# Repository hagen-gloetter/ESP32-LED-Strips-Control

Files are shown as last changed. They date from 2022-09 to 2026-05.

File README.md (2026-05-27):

# ESP32 LED-Strips Control — Sternwarte Höfingen

> **[Deutsch](#deutsch)** · **[English](#english)**

---

## 🇩🇪 Deutsch

### Projektbeschreibung

Steuerung der Beleuchtung der [Sternwarte Höfingen](https://www.sternwarte-hoefingen.de) über drei RGB-LED-Streifen an einem ESP32. Das System unterstützt rotes Beobachtungslicht (schonend für die Dunkeladaption) und weißes Allgemeinlicht. Helligkeit und Farbe sind über Drucktasten, einen Drehgeber und eine eingebaute Weboberfläche (Port 80) einstellbar. Ein DHT11-Sensor misst Temperatur und Luftfeuchtigkeit und zeigt sie im Web-UI an.

---

### Hardware

| Komponente | Beschreibung |
|---|---|
| ESP32 AZ-Delivery D1 Mini | Hauptcontroller |
| 3× RGB-LED-Streifen | Common-cathode, PWM-gesteuert |
| 2× Drucktaster (NO) | Weiß-/Rotlicht-Toggle |
| 1× Drehgeber mit Taster | Helligkeit |
| 1× DHT11 | Temperatur + Luftfeuchtigkeit |

#### GPIO-Belegung

| GPIO | Signal | Komponente |
|---|---|---|
| 0 | DHT DATA | DHT11 |
| 27 | STRIP 1 R | LED-Strip 1 Rot |
| 25 | STRIP 1 G | LED-Strip 1 Grün |
| 32 | STRIP 1 B | LED-Strip 1 Blau |
| 22 | STRIP 2 R | LED-Strip 2 Rot |
| 21 | STRIP 2 G | LED-Strip 2 Grün |
| 17 | STRIP 2 B | LED-Strip 2 Blau |
| 19 | STRIP 3 R | LED-Strip 3 Rot |
| 18 | STRIP 3 G | LED-Strip 3 Grün |
| 26 | STRIP 3 B | LED-Strip 3 Blau |
| 13 | BUTTON_W | Weiß-Taster (T1) |
| 10 | BUTTON_R | Rot-Taster (T2) |
| 14 | BUTTON_D | Drehgeber-Taster |
| 33 | CLK | Drehgeber CLK |
| 34 | DT | Drehgeber DT |
| 2 | LED | Onboard-LED (Status) |

#### Verdrahtungsdiagramm

```mermaid
graph TD
    subgraph ESP32["ESP32 D1 Mini"]
        G0["GPIO 0"]
        G2["GPIO 2"]
        G10["GPIO 10"]
        G13["GPIO 13"]
        G14["GPIO 14"]
        G17["GPIO 17"]
        G18["GPIO 18"]
        G19["GPIO 19"]
        G21["GPIO 21"]
        G22["GPIO 22"]
        G25["GPIO 25"]
        G26["GPIO 26"]
        G27["GPIO 27"]
        G32["GPIO 32"]
        G33["GPIO 33"]
        G34["GPIO 34"]
    end

    DHT11["DHT11\nTemp + Humidity"]
    BW["Button Weiß\n(T1, PULL_UP)"]
    BR["Button Rot\n(T2, PULL_UP)"]
    BD["Rotary SW\n(PULL_UP)"]
    RCLK["Rotary CLK\n(IRQ)"]
    RDT["Rotary DT\n(IRQ)"]
    ONBLED["Onboard LED"]

    subgraph Strip1["LED Strip 1"]
        S1R["Red"]
        S1G["Green"]
        S1B["Blue"]
    end
    subgraph Strip2["LED Strip 2"]
        S2R["Red"]
        S2G["Green"]
        S2B["Blue"]
    end
    subgraph Strip3["LED Strip 3"]
        S3R["Red"]
        S3G["Green"]
        S3B["Blue"]
    end

    G0  -->|DATA| DHT11
    G2  --> ONBLED
    G13 -->|IN| BW
    G10 -->|IN| BR
    G14 -->|IN| BD
    G33 -->|IN| RCLK
    G34 -->|IN| RDT
    G27 -->|PWM| S1R
    G25 -->|PWM| S1G
    G32 -->|PWM| S1B
    G22 -->|PWM| S2R
    G21 -->|PWM| S2G
    G17 -->|PWM| S2B
    G19 -->|PWM| S3R
    G18 -->|PWM| S3G
    G26 -->|PWM| S3B
```

---

### Licht-Logik

| Aktion | Ergebnis |
|---|---|
| Weiß-Taster (kurz) | Weißlicht ON/OFF (Rot hat Vorrang) |
| Rot-Taster (kurz) | Rotlicht ON; schaltet Weiß ab wenn nötig |
| Weiß 2× schnell (<2 s) | Helligkeit 50% |
| Weiß 4× schnell (<2 s) | Helligkeit 25% |
| Weiß 10× schnell (<6 s) | Easter Egg: Rainbow |
| Rot 2× schnell (<2 s) | Helligkeit 50% |
| Rot 4× schnell (<2 s) | Helligkeit 25% |
| Rot 10× schnell (<6 s) | Easter Egg: Zufallsfarben |
| Weiß/Rot gehalten (>500 ms) | Hold-to-Dim bis Mindesthelligkeit |
| Drehgeber rechts | Helligkeit erhöhen (2^Wert, max 1024) |
| Drehgeber links | Helligkeit verringern |
| Auto-Off | Schaltet nach konfigurierbarer Zeit automatisch aus |

PWM-Frequenz: **7321 Hz** (Primzahl, verhindert Moire-Artefakte in Kameras und Augen)

---

### Software / Abhängigkeiten

| | |
|---|---|
| MicroPython-Firmware | ≥ v1.19.1 für ESP32 |
| `dht` | Built-in in MicroPython |
| `ujson` | Built-in in MicroPython |
| `network` | Built-in in MicroPython |
| `rotary.py` | Mitgeliefert (MIT License, Mike Teachman) |

---

### Konfiguration

#### Konstanten in `config.json`

Konstanten können in `config.json` angepasst werden (Fallback auf Defaults bei Fehler):

| Konstante | Standardwert | Beschreibung |
|---|---|---|
| `LOOP_MS` | `100` | Haupt-Loop-Takt in ms (10 Hz) |
| `WIFI_CHECK_TICKS` | `300` | WiFi-Check alle 300 × 100 ms = 30 s |
| `Brightness` | `1024` | Anfangshelligkeit (0–1023) |
| `Fade_speed` | `16` | Fade-Schrittgröße pro Timer-Tick (1–64) |
| `DebugLevel` | `4` | 1=Fehler, 2=Warn, 3=Info, 4=verbose |
| `auto_off_minutes` | `120` | Auto-Off Timer in Minuten (0 = deaktiviert) |
| `hostname` | `ESP32-Huettenlicht` | WiFi DHCP-Hostname |
| `rotary_encoder_enabled` | `0` | Drehgeber-Auswertung aktiv (`1`) oder deaktiviert (`0`) |

WDT-Timeout: **15 000 ms** (> WiFi-Connect-Timeout von 10 000 ms).

#### Secrets-Datei

Lege `secrets_wifi.json` auf dem Gerät an (Format wie `secrets_wifi_example.json`):

```json
{
    "MeinHeimnetzwerk": "MeinPasswort",
    "FallbackSSID": "FallbackPasswort"
}
```

Das Gerät scannt verfügbare Netze und verbindet sich automatisch mit dem ersten bekannten SSID.

---

### WebREPL

Einmalige Einrichtung (einmalig im REPL):

```python
import webrepl_setup
```

Passwort wird in `webrepl_cfg.py` gespeichert (Standard: `1234` – **bitte ändern**).

Danach erreichbar unter: `ws://<IP des ESP32>:8266`  
Tool: [http://micropython.org/webrepl/](http://micropython.org/webrepl/)

---

### Weboberfläche

Modernes, responsives Dark-Theme-UI (Astronomie-optimiert), vollständig self-contained (kein externes CSS/JS). Features:

- **Card-basiertes Layout** mit Flexbox/Grid (responsive, mobiltauglich)
- **HTML5 Color-Picker** mit Live-Farbvorschau und RGB-Nummernfeldern
- **Farb-Presets** als visuelles Button-Grid (Rot, Grün, Blau, Weiß, Gelb, Lila, Cyan, Orange)
- **Aktiver ON/OFF-State** mit visuellem Glow-Feedback
- **Verstecktes Easter-Egg-Panel** mit Rainbow/Random/Stop
- **Config-Seite** für Fade Speed, Auto-Off, Debug Level, Hostname, Rotary Encoder ON/OFF und Reset
- **Vanilla JS** (kein jQuery), Polling via `fetch()` alle 4 Sekunden

| URL-Pfad | Funktion |
|---|---|
| `/` | Haupt-UI (HTML) |
| `/?red=on` / `/?red=off` | Rotlicht ein/aus |
| `/?white=on` / `/?white=off` | Weißlicht ein/aus |
| `/?r=R&g=G&b=B` | RGB-Wert direkt setzen (0–255) |
| `/?easter=rainbow` / `random` / `off` | Easter Egg steuern |
| `/?config_save&fade=N&autooff=N&debug=N&host=X&rotary=0|1` | Konfiguration speichern |
| `/?reset=1` | ESP32 Neustart |
| `/config.html` | Konfigurationsseite |
| `/data.json` | Aktueller Status als JSON |
| `/web.css` | Stylesheet |
| `/debug.html` | Live-Debug-Log |
| `/logs.html` | Separate Logs-Webseite |
| `/logs.json` | Logs als JSON für Polling |

---

### Dateistruktur

```
code/
├── boot.py                  # Startup: startet WebREPL
├── main.py                  # Hauptanwendung (GPIO, Webserver, Loop)
├── config.json              # Konfigurationsdatei für Konstanten
├── class_pwm.py             # RGB-LED-Strip PWM-Treiber
├── class_debounce.py        # Software-Entprellung für Tasten
├── class_debug.py           # Ring-Buffer Debug-Logger
├── class_humidity_sensor.py # DHT11-Treiber
├── class_wifi_connection.py # Multi-SSID WiFi-Manager
├── class_rotary_encoder.py  # Drehgeber (ESP32 IRQ)
├── rotary.py                # Plattformunabhängige Basis-Klasse (extern)
├── rotary_encoder.py        # Standalone-Beispiel (nicht im Hauptpfad)
├── rotary_irq_esp.py        # Standalone-Beispiel (nicht im Hauptpfad)
├── web_html.py              # HTML/CSS/Debug-Templates
├── webrepl_cfg.py           # WebREPL-Passwort
└── secrets_wifi_example.json # Beispiel für WiFi-Zugangsdaten
```

---

### Flash / Deployment

**Firmware flashen (einmalig):**

```bash
pip install esptool
esptool.py --chip esp32 --port /dev/ttyUSB0 erase_flash
esptool.py --chip esp32 --port /dev/ttyUSB0 write_flash -z 0x1000 \
    esp32-20220618-v1.19.1.bin
```

**Dateien übertragen (mpremote):**

```bash
pip install mpremote
mpremote connect /dev/ttyUSB0 cp code/secrets_wifi.json :secrets_wifi.json
mpremote connect /dev/ttyUSB0 cp code/boot.py :boot.py
mpremote connect /dev/ttyUSB0 cp code/main.py :main.py
mpremote connect /dev/ttyUSB0 cp code/class_*.py :/
mpremote connect /dev/ttyUSB0 cp code/rotary.py :rotary.py
mpremote connect /dev/ttyUSB0 cp code/web_html.py :web_html.py
mpremote connect /dev/ttyUSB0 cp code/webrepl_cfg.py :webrepl_cfg.py
```

**Alternativ mit Thonny:** [https://thonny.org/](https://thonny.org/)

---

### Bekannte Einschränkungen / TODOs

- `Strip3` wird in der aktuellen Hauptschleife nicht über den Webserver-RGB-Pfad gesetzt (nur Strip 1 und 2). Geplant: Übergabe einer Strip-Liste.
- RGB-Eingabe im Web-UI akzeptiert Werte 0–255; intern wird 0–1023 verwendet (PWM-Auflösung ESP32). Die Webserver-Validierung begrenzt auf 255 — für volle Auflösung Code anpassen.
- `rotary_encoder.py` und `rotary_irq_esp.py` sind Standalone-Beispiele und kein Bestandteil des Hauptprogramms — können vom Gerät gelöscht werden.

---

### Changelog

Siehe [CHANGELOG.md](CHANGELOG.md).

---

### Lizenz

Siehe [LICENSE](LICENSE).

---
---

## 🇬🇧 English

### Project Description

Controls the lighting of the [Sternwarte Höfingen observatory](https://www.sternwarte-hoefingen.de) via three RGB LED strips driven by an ESP32. The system supports red observation light (preserves dark adaption) and white general lighting. Brightness and colour are adjustable via push buttons, a rotary encoder, and a built-in web interface on port 80. A DHT11 sensor measures ambient temperature and humidity, displayed in the web UI.

---

### Hardware

| Component | Description |
|---|---|
| ESP32 AZ-Delivery D1 Mini | Main controller |
| 3× RGB LED strip | Common-cathode, PWM-controlled |
| 2× push button (NO) | White/red light toggle |
| 1× rotary encoder with button | Brightness |
| 1× DHT11 | Temperature + humidity |

#### GPIO mapping

| GPIO | Signal | Component |
|---|---|---|
| 0 | DHT DATA | DHT11 |
| 27 | STRIP 1 R | LED Strip 1 Red |
| 25 | STRIP 1 G | LED Strip 1 Green |
| 32 | STRIP 1 B | LED Strip 1 Blue |
| 22 | STRIP 2 R | LED Strip 2 Red |
| 21 | STRIP 2 G | LED Strip 2 Green |
| 17 | STRIP 2 B | LED Strip 2 Blue |
| 19 | STRIP 3 R | LED Strip 3 Red |
| 18 | STRIP 3 G | LED Strip 3 Green |
| 26 | STRIP 3 B | LED Strip 3 Blue |
| 13 | BUTTON_W | White button (T1) |
| 10 | BUTTON_R | Red button (T2) |
| 14 | BUTTON_D | Rotary encoder push button |
| 33 | CLK | Rotary encoder CLK |
| 34 | DT | Rotary encoder DT |
| 2 | LED | On-board LED (status) |

#### Wiring Diagram

```mermaid
graph TD
    subgraph ESP32["ESP32 D1 Mini"]
        G0["GPIO 0"]
        G2["GPIO 2"]
        G10["GPIO 10"]
        G13["GPIO 13"]
        G14["GPIO 14"]
        G17["GPIO 17"]
        G18["GPIO 18"]
        G19["GPIO 19"]
        G21["GPIO 21"]
        G22["GPIO 22"]
        G25["GPIO 25"]
        G26["GPIO 26"]
        G27["GPIO 27"]
        G32["GPIO 32"]
        G33["GPIO 33"]
        G34["GPIO 34"]
    end

    DHT11["DHT11\nTemp + Humidity"]
    BW["Button White\n(T1, PULL_UP)"]
    BR["Button Red\n(T2, PULL_UP)"]
    BD["Rotary SW\n(PULL_UP)"]
    RCLK["Rotary CLK\n(IRQ)"]
    RDT["Rotary DT\n(IRQ)"]
    ONBLED["Onboard LED"]

    subgraph Strip1["LED Strip 1"]
        S1R["Red"]
        S1G["Green"]
        S1B["Blue"]
    end
    subgraph Strip2["LED Strip 2"]
        S2R["Red"]
        S2G["Green"]
        S2B["Blue"]
    end
    subgraph Strip3["LED Strip 3"]
        S3R["Red"]
        S3G["Green"]
        S3B["Blue"]
    end

    G0  -->|DATA| DHT11
    G2  --> ONBLED
    G13 -->|IN| BW
    G10 -->|IN| BR
    G14 -->|IN| BD
    G33 -->|IN| RCLK
    G34 -->|IN| RDT
    G27 -->|PWM| S1R
    G25 -->|PWM| S1G
    G32 -->|PWM| S1B
    G22 -->|PWM| S2R
    G21 -->|PWM| S2G
    G17 -->|PWM| S2B
    G19 -->|PWM| S3R
    G18 -->|PWM| S3G
    G26 -->|PWM| S3B
```

---

### Light Logic

| Action | Result |
|---|---|
| White button (short) | Toggle white light ON/OFF (red takes priority) |
| Red button (short) | Red light ON; switches white off if needed |
| White 2× fast (<2 s) | Set brightness to 50% |
| White 4× fast (<2 s) | Set brightness to 25% |
| White 10× fast (<6 s) | Easter Egg: rainbow |
| Red 2× fast (<2 s) | Set brightness to 50% |
| Red 4× fast (<2 s) | Set brightness to 25% |
| Red 10× fast (<6 s) | Easter Egg: random colours |
| White/Red held (>500 ms) | Hold-to-dim down to a safe minimum |
| Rotary encoder CW | Increase brightness (2^value, max 1024) |
| Rotary encoder CCW | Decrease brightness |
| Auto-Off | Turns lights off after a configurable timeout |

PWM frequency: **7321 Hz** (prime number, avoids moiré artefacts in cameras and eyes).

---

### Software / Dependencies

| | |
|---|---|
| MicroPython firmware | ≥ v1.19.1 for ESP32 |
| `dht` | Built-in MicroPython |
| `ujson` | Built-in MicroPython |
| `network` | Built-in MicroPython |
| `rotary.py` | Bundled (MIT License, Mike Teachman) |

---

### Configuration

#### Constants in `config.json`

| Constant | Default | Description |
|---|---|---|
| `LOOP_MS` | `100` | Main loop interval in ms (10 Hz) |
| `WIFI_CHECK_TICKS` | `300` | WiFi health check every 300 × 100 ms = 30 s |
| `Brightness` | `1024` | Initial brightness (0–1023) |
| `Fade_speed` | `16` | Fade step size per timer tick (1–64) |
| `DebugLevel` | `4` | 1=error, 2=warn, 3=info, 4=verbose |
| `auto_off_minutes` | `120` | Auto-off timer in minutes (0 = disabled) |
| `hostname` | `ESP32-Huettenlicht` | WiFi DHCP hostname |
| `rotary_encoder_enabled` | `0` | Enable (`1`) or disable (`0`) rotary encoder handling |

WDT timeout: **15 000 ms** (> WiFi connect timeout of 10 000 ms).

#### Secrets file

Create `secrets_wifi.json` on the device (format as in `secrets_wifi_example.json`):

```json
{
    "MyHomeNetwork": "MyPassword",
    "FallbackSSID": "FallbackPassword"
}
```

The device scans for available networks and connects to the first known SSID.

---

### WebREPL

One-time setup (run once in REPL):

```python
import webrepl_setup
```

The password is stored in `webrepl_cfg.py` (default: `1234` — **please change**).

Then accessible at: `ws://<ESP32 IP>:8266`  
Tool: [http://micropython.org/webrepl/](http://micropython.org/webrepl/)

---

### Web Interface

Modern, responsive dark-theme UI (optimised for astronomy use), fully self-contained (no external CSS/JS). Features:

- **Card-based layout** using Flexbox/Grid (responsive, mobile-friendly)
- **HTML5 colour picker** with live colour preview and RGB number inputs
- **Colour presets** as a visual button grid (red, green, blue, white, yellow, purple, cyan, orange)
- **Active ON/OFF state** with visual glow feedback
- **Hidden Easter Egg panel** with rainbow/random/stop actions
- **Config page** for fade speed, auto-off, debug level, hostname, rotary encoder ON/OFF, and reset
- **Vanilla JS** (no jQuery), polling via `fetch()` every 4 seconds

| URL path | Function |
|---|---|
| `/` | Main control UI (HTML) |
| `/?red=on` / `/?red=off` | Red light on/off |
| `/?white=on` / `/?white=off` | White light on/off |
| `/?r=R&g=G&b=B` | Set RGB directly (0–255) |
| `/?easter=rainbow` / `random` / `off` | Control Easter Egg modes |
| `/?config_save&fade=N&autooff=N&debug=N&host=X&rotary=0|1` | Save configuration |
| `/?reset=1` | Reboot the ESP32 |
| `/config.html` | Configuration page |
| `/data.json` | Current state as JSON |
| `/web.css` | Stylesheet |
| `/debug.html` | Live debug log |
| `/logs.html` | Logs page |
| `/logs.json` | Logs as JSON for polling |

---

### File Structure

```
code/
├── boot.py                  # Startup: starts WebREPL
├── main.py                  # Main application (GPIO, webserver, loop)
├── class_pwm.py             # RGB LED strip PWM driver
├── class_debounce.py        # Software button debounce
├── class_debug.py           # Ring-buffer debug logger
├── class_humidity_sensor.py # DHT11 driver
├── class_wifi_connection.py # Multi-SSID WiFi manager
├── class_rotary_encoder.py  # Rotary encoder (ESP32 IRQ)
├── rotary.py                # Platform-independent base class (3rd party)
├── rotary_encoder.py        # Standalone example (not in main path)
├── rotary_irq_esp.py        # Standalone example (not in main path)
├── web_html.py              # HTML/CSS/debug templates
├── webrepl_cfg.py           # WebREPL password
└── secrets_wifi_example.json # Example WiFi credentials
```

---

### Flash / Deployment

**Flash firmware (once):**

```bash
pip install esptool
esptool.py --chip esp32 --port /dev/ttyUSB0 erase_flash
esptool.py --chip esp32 --port /dev/ttyUSB0 write_flash -z 0x1000 \
    esp32-20220618-v1.19.1.bin
```

**Transfer files (mpremote):**

```bash
pip install mpremote
mpremote connect /dev/ttyUSB0 cp code/secrets_wifi.json :secrets_wifi.json
mpremote connect /dev/ttyUSB0 cp code/boot.py :boot.py
mpremote connect /dev/ttyUSB0 cp code/main.py :main.py
mpremote connect /dev/ttyUSB0 cp code/class_*.py :/
mpremote connect /dev/ttyUSB0 cp code/rotary.py :rotary.py
mpremote connect /dev/ttyUSB0 cp code/web_html.py :web_html.py
mpremote connect /dev/ttyUSB0 cp code/webrepl_cfg.py :webrepl_cfg.py
```

**Alternatively with Thonny:** [https://thonny.org/](https://thonny.org/)

---

### Known Limitations / TODOs

- `Strip3` is not updated via the web-UI RGB path (only Strip 1 and 2). Planned: pass a strip list as a parameter.
- The web UI RGB inputs accept 0–255; internally 0–1023 is used (ESP32 PWM resolution). For full resolution, update the web-server validation.
- `rotary_encoder.py` and `rotary_irq_esp.py` are standalone examples and not part of the main application — they can be deleted from the device.

---

### Changelog

See [CHANGELOG.md](CHANGELOG.md).

---

### License

See [LICENSE](LICENSE).

What we need:
Software:

* MicroPython IDE
  * https://thonny.org/ 
  * or choco install thonny
  
* MicroPython Firmware
  * https://micropython.org/download/esp32/

* Windows Diver for ESP32
  * https://www.silabs.com/developers/usb-to-uart-bridge-vcp-drivers?tab=downloads
  * https://www.silabs.com/documents/public/software/CP210x_Windows_Drivers.zip

* Pinout ESP32 WROOM
  https://randomnerdtutorials.com/esp32-pinout-reference-gpios/
* 

Hardware:

* ESP 32

  https://www.az-delivery.de/products/esp32-d1-mini?variant=32437195505760

Tutorial 4 MicroPython: 

* https://www.youtube.com/watch?v=elBtWZ_fOZU

Steps:
pip install esptool
esptool.py --port /dev/ttyUSB0 erase_flash
https://micropython.org/download/esp32/ --> downloads --> https://micropython.org/resources/firmware/esp32-20220618-v1.19.1.bin
esptool.py --chip esp32 --port /dev/ttyUSB0 write_flash -z 0x1000 ~/Downloads/esp32-20220618-v1.19.1.bin

After that Python is ready to run on the ESP32

After booting, the ESP32 with MicroPython will execute 2 files - boot.py and main.py, by this order. If boot.py exists, it´s executed first and then main.py.

If you want something to be executed at boot, put the code in main.py or boot.py

To execute the code every time the ESP32 turns on, we should put the above code in a file named main.py or boot.py and copy it to the ESP32

try: 
```python
import machine
import time
led = machine.Pin(2, machine.Pin.OUT)
while True:
	led.value(1)
	time.sleep(1)
	led.value(0)
	time.sleep(1)
```

At this point in time, you will be able to enable WebREPL on your ESP32 board. In order to do so, enter the following Python codes into the REPL prompt:

```python
import webrepl_setup
```

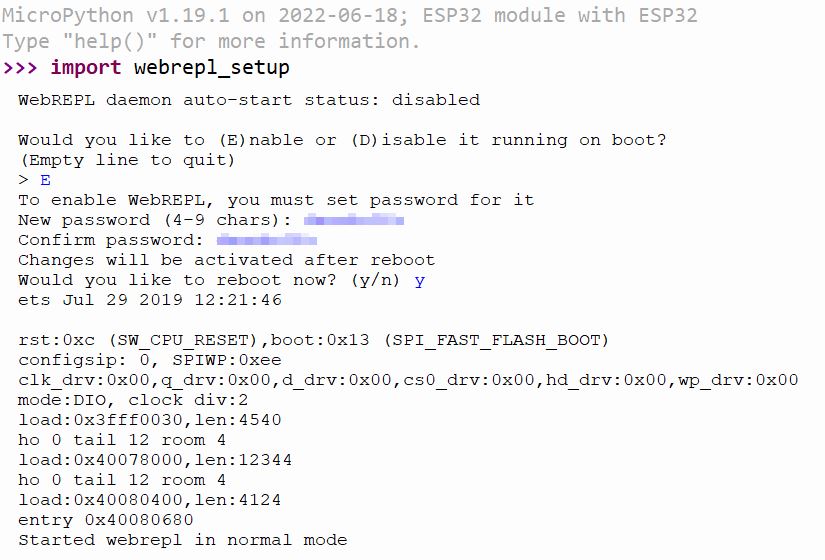
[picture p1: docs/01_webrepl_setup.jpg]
webrepl_setup


Edit the file on the ESP: boot.py
```python
ssid = 'www.hagenfragen.de'
password = 'i-do-not-tell-ya'
import network
import webrepl
def do_connect(ssid, pwd):
    sta_if = network.WLAN(network.STA_IF)
    if not sta_if.isconnected():
        print('connecting to network...')
        sta_if.active(True)
        sta_if.connect(ssid, pwd)
        while not sta_if.isconnected():
            pass
    print('network config:', sta_if.ifconfig())
 
# This file is executed on every boot (including wake-boot from deepsleep)
#import esp
#esp.osdebug(None)
 
# Attempt to connect to WiFi network
do_connect(ssid, password)
webrepl.start()
```

Now we can work with the ESP32 remotely via IP.

Why stop here? Now we go for the webserver

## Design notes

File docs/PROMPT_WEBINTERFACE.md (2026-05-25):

# Prompt: Webinterface Modernisierung

Arbeite ausschließlich im Ordner `code/` dieses Projekts. Das Projekt steuert RGB-LED-Strips an einem ESP32 (MicroPython) für eine Sternwarte. Die Datei `web_html.py` enthält das gesamte Webinterface (HTML/CSS/JS als Python-Strings), das vom ESP32 auf Port 80 ausgeliefert wird.

**Aufgabe:** Überarbeite das Webinterface in `web_html.py` (Funktionen `web_page()` und `web_css()`) zu einem modernen, interaktiven Single-Page-UI:

- **Layout:** Ersetze die Tabellen-Struktur durch ein responsives CSS-Grid/Flexbox-Layout mit Cards/Panels für die Bereiche: Lichtsteuerung (On/Off), RGB-Farbwahl, Presets, Sensorwerte (Temperatur/Feuchtigkeit), Systeminformationen.
- **Farbwahl:** Füge einen interaktiven HTML5 Color-Picker (`<input type="color">`) hinzu, der die RGB-Werte in Echtzeit an den ESP32 sendet (via XHR/fetch an die bestehenden Endpunkte `/?r=X&g=X&b=X`). Behalte die numerischen RGB-Inputs als Alternative bei.
- **Visuelles Feedback:** Zeige eine Live-Farbvorschau (farbiges Div) der aktuell gesetzten RGB-Werte. Buttons sollen den aktuellen Zustand (ON/OFF) visuell hervorheben (aktiver State).
- **Styling:** Dunkles Theme (passend zur Sternwarte/Astronomie), abgerundete Buttons, sanfte Transitions, dezente Schatten. Moderne Typografie (system-font-stack).
- **Constraints:** Kein externes CSS-Framework (kein Bootstrap etc.) – alles muss inline oder über `web_css()` geliefert werden, da der ESP32 begrenzte Ressourcen hat. Kein jQuery – nutze Vanilla JS. Halte die Gesamtgröße des HTML/CSS/JS kompakt (ESP32-RAM ist limitiert). Die bestehende Polling-Logik (`data.json` alle 4s) und alle existierenden Endpunkte müssen weiterhin funktionieren.

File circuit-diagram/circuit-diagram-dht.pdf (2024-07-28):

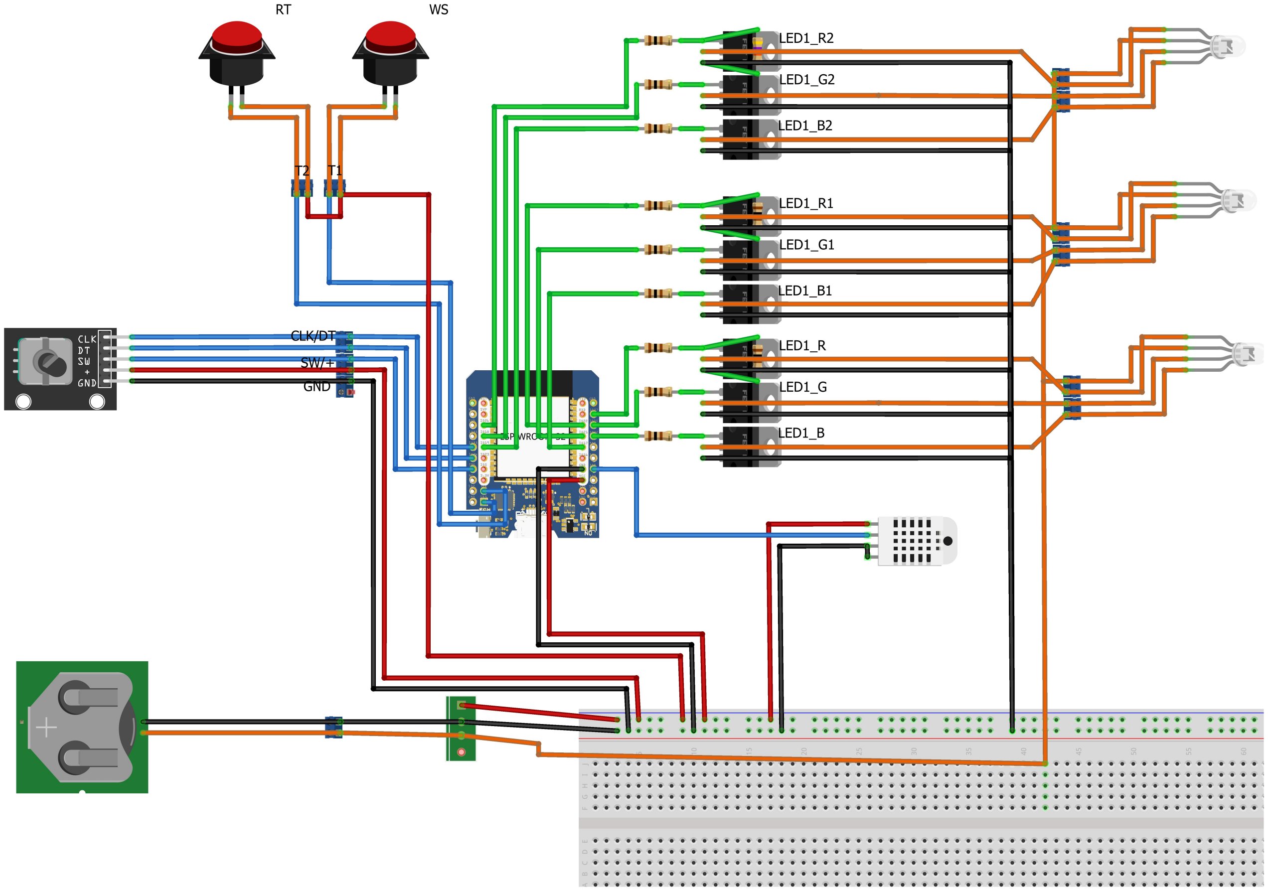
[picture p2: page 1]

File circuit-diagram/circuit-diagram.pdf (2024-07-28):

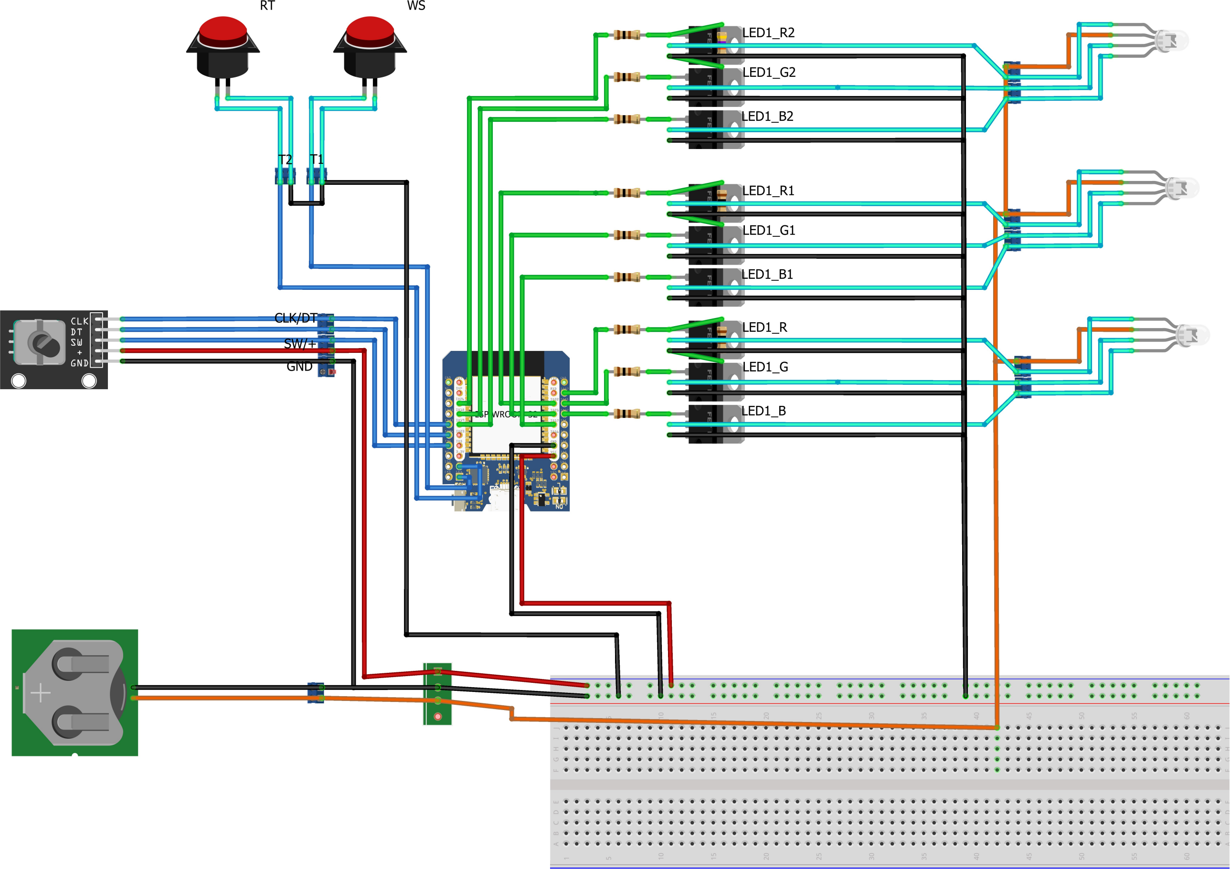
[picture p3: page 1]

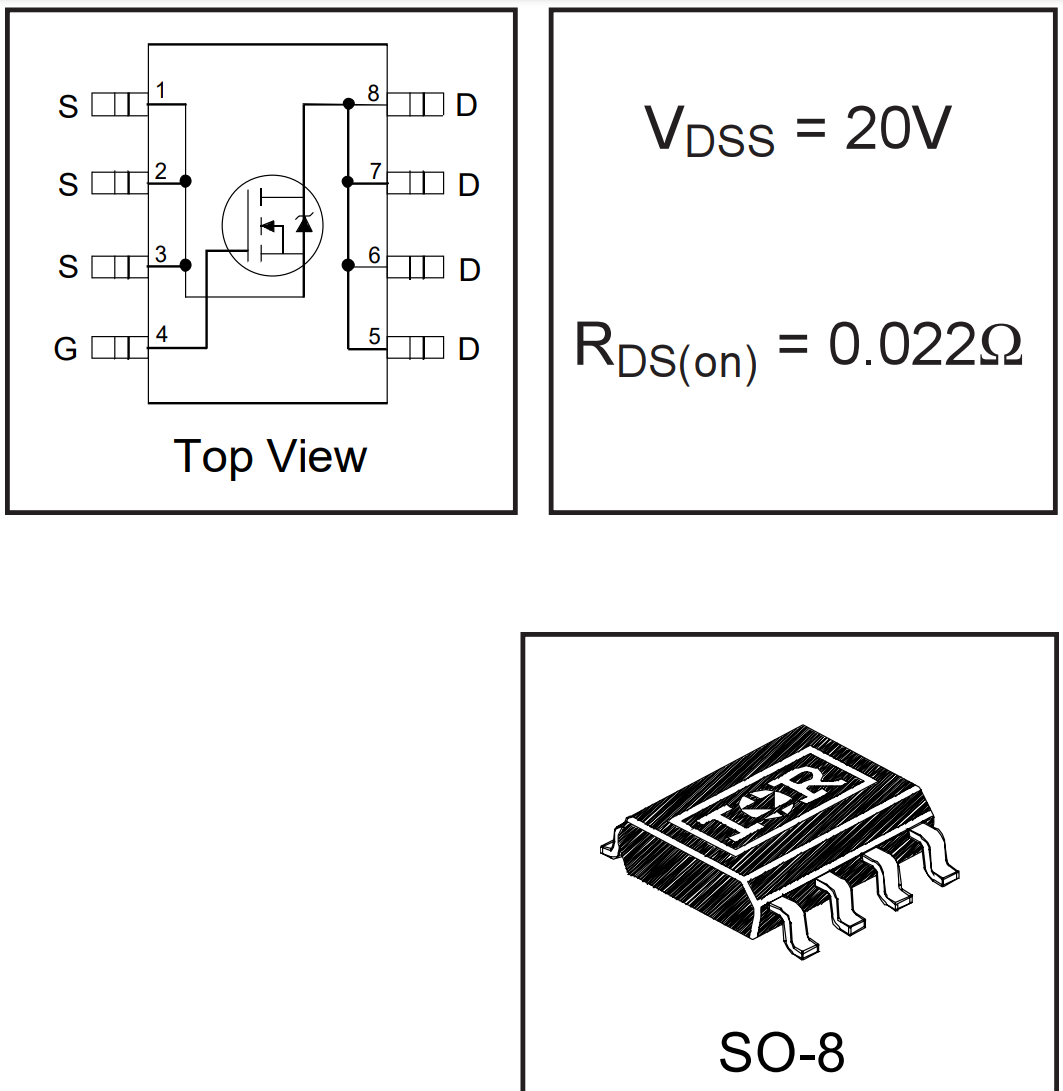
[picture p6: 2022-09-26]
Datasheets/IRF7401PbF.PMD.png

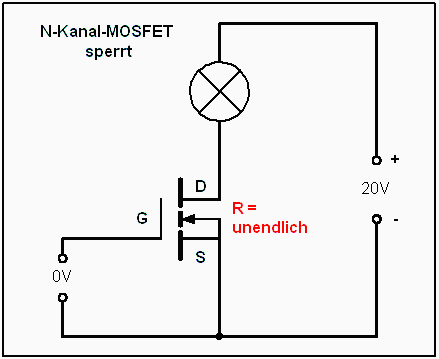
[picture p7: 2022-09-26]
Datasheets/mosfe-tnsperr.gif

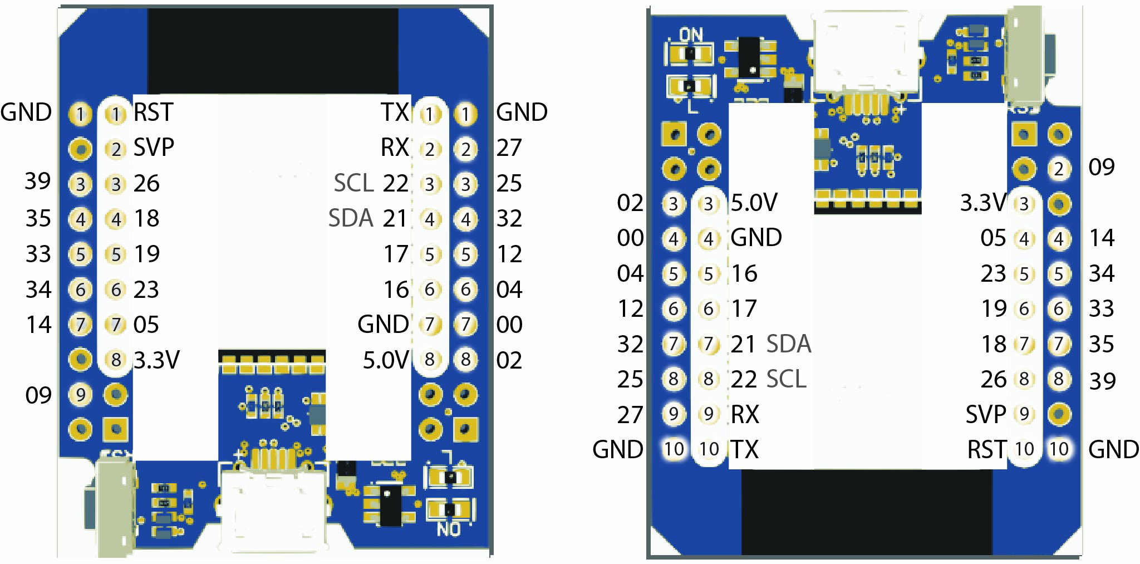
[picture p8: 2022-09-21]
Datasheets/ESP32-D1-GPIOs.jpg

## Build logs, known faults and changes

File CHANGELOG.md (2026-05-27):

# Changelog

All notable changes to this project will be documented in this file.  
Format follows [Keep a Changelog](https://keepachangelog.com/en/1.0.0/).

---

## [Unreleased]

---

## [Session 6] — 2026-05-27

### Added

- **Easter Eggs** — Button_W 10× in 6s → Rainbow-Effekt, Button_R 10× → Zufallsfarben. Deaktivierung durch beliebigen Tastendruck oder über Web-UI.
- **Rapid-Press Helligkeitssteuerung** — 2× drücken = 50%, 4× = 25%.
- **Hold-to-Dim** — Taste gehalten (>500 ms) reduziert die Helligkeit progressiv.
- **Auto-Off Timer** — Konfigurierbar (0–480 min, Default 120 min) und aktiv für Lichtmodi sowie Easter Eggs.
- **Konfigurations-Webseite** — Neue Route `/config.html` für Fade Speed, Auto-Off Timer, Debug Level und WiFi Hostname.
- **WiFi Hostname** — Konfigurierbarer DHCP-Hostname mit Default `ESP32-Huettenlicht`.
- **Reset-Button im Web-UI** — Neustart des ESP32 direkt aus der Config-Seite, abgesichert mit Bestätigungsdialog.
- **Rotary Encoder ON/OFF** — Neuer Web-Schalter in der Config-Seite. Default ist OFF, Status wird in `config.json` gespeichert.

### Changed

- **`set_JSON()` auf `ujson.dumps()` umgestellt** — Weniger String-Konkatenation, neue Statusfelder für `auto_off_minutes`, `easter_egg` und `hostname`, Helligkeit jetzt als Prozent.
- **Debug/Logs-Seiten redesigned** — Shared CSS, Card-Layout, Scroll-Container und Navigation zurück zur Hauptseite.
- **Hauptseite erweitert** — System-Card zeigt jetzt Links zu Einstellungen, Logs, Debug sowie Live-Infos für Auto-Off und Easter Egg Status.
- **Rainbow-Modus verbessert** — Direkte HSV→RGB-Berechnung pro Tick hält die Helligkeit konstant.
- **Random-Modus verbessert** — Zufallsfarben werden jetzt aus HSV generiert und wirken satter.
- **Optionaler Drehgeber sauber behandelt** — Bei OFF wird die Encoder-IRQ-Verarbeitung deaktiviert statt nur das Ergebnis zu ignorieren.

### Fixed

- **BUG-14** — `main.py` `thread_webserver()`: Fehlende `global`-Deklarationen für Web-Änderungen (`EasterEgg_Mode`, Auto-Off, Config-Werte, Hostname). Ohne `global` liefen Web-Änderungen nur lokal im Thread und hatten keine Wirkung auf die eigentliche Steuerlogik. **Severity: CRITICAL**
- **BUG-15** — `main.py` RGB-Parsing: Der Blauwert wurde bis ins HTTP-Header-Ende gelesen (`"...HTTP/1.1\r\n"`) und ließ Web-RGB-Kommandos abstürzen. Jetzt wird sauber am Leerzeichen bzw. `&` terminiert. **Severity: HIGH**
- **BUG-16** — `main.py` Config-Save: Nach Einführung des Hostname-Parameters wurde der Debug-Wert als `"4&host=..."` gelesen und konnte nicht mehr in `int` umgewandelt werden. Jetzt wird zuerst an `&` terminiert. **Severity: HIGH**
- **Easter Egg State Leak** — Beim Abbruch werden jetzt Hue, Zähler und Auto-Off-Start sauber zurückgesetzt.
- **Custom RGB Override** — Web-RGB deaktiviert jetzt Weiß-/Rotmodus und Easter Egg, damit die Farbe nicht sofort überschrieben wird.

---

## [Session 5] — 2026-05-26

### Changed

- **Webinterface komplett überarbeitet** — `web_html.py`: Tabellen-basiertes Layout durch modernes Card-basiertes Dark-Theme-UI ersetzt. Flexbox/Grid-Layout, responsive, mobiltauglich.
- **HTML5 Color-Picker** — Interaktiver `<input type="color">` mit Live-Farbvorschau-Div. RGB-Nummernfelder weiterhin als Alternative vorhanden.
- **Farb-Presets als visuelles Grid** — 8 Preset-Buttons mit farbigem Hintergrund statt Tabellen-Zeilen.
- **ON/OFF-State-Feedback** — Aktive Buttons erhalten Glow-Effekt via `classList.toggle('active')`.
- **Dark-Theme (Astronomie)** — Dunkler Hintergrund (#0d1117), GitHub-Dark-Farbpalette, abgerundete Cards, sanfte Transitions.
- **jQuery entfernt** — `debug_web_page()` und `logs_web_page()` nutzen nun Vanilla JS mit `fetch()` statt jQuery-CDN.
- **XHR durch fetch() ersetzt** — Alle HTTP-Aufrufe (Polling, Kommandos) nutzen nun die Fetch-API.
- **CSS modernisiert** — System-Font-Stack, CSS-Custom-Properties für Preset-Farben, kompaktes minifiziertes CSS (~2.8 KB).

---

## [Session 4] — 2026-03-28

### Added

- **IMP-03** — Separate Logs-Webseite: Neue Route `/logs.html` und `/logs.json` für Live-Debug-Logging. Pollt alle 5s für kontinuierliche Anzeige.
- **Konfigurationsdatei** — `config.json`: Konstanten (Brightness, Fade_speed, etc.) ausgelagert für einfache Anpassung ohne Code-Änderung.
- **Mehr Presets im Webinterface** — Zusätzliche Farb-Presets: Gelb, Lila, Cyan, Orange. Erweitert Benutzerfreundlichkeit.
- **Erweiterte Logging** — Mehr Debug-Nachrichten für Edge-Cases: DHT11-Fehler, Rotary-Encoder-Status, WiFi-Scan-Ergebnisse.

### Changed

- **WiFi-Check-Intervall** — Von 60s auf 30s reduziert für schnellere Reconnect-Erkennung.
- **RGB-Skalierung** — Web-Eingaben (0-255) werden auf interne PWM-Auflösung (0-1023) skaliert für volle Helligkeit.
- **Strip3-Integration** — Alle drei LED-Strips werden nun bei RGB-Web-Updates und Fading aktualisiert.
- **Code-Deduplikation** — Neue Funktion `update_all_strips()` für Strip-Updates. Reduziert Wiederholungen.
- **Button-Debounce** — `debounceTime` von 5 auf 10 Zyklen erhöht für robustere Fehleingabe-Verhinderung.
- **Webinterface-Layout** — Getrennte Eingabefelder für R, G, B mit Presets. Verbessert Usability.

---

### Fixed

- **BUG-01** — `class_wifi_connection.py` `connect()`: `ujson.load(open(fn_secrets))` leaked the file handle. Replaced with `with open(fn_secrets) as f: ujson.load(f)`.
- **BUG-02** — `class_wifi_connection.py` `connect()`: Bare `except:` swallowed all errors silently. Changed to `except Exception as e:` with the error included in the debug message.
- **BUG-03** — `main.py` `thread_webserver()`: `conn` was not initialised to `None` before the `try` block. If `websocket.accept()` raised an exception, the `except` block then called `conn.close()` which caused `NameError`. Added `conn = None` guard and `if conn is not None` check in `except`.
- **BUG-04** — `main.py` `get_websocket()`: Missing `SO_REUSEADDR` socket option. After a crash, port 80 remained busy for the TCP TIME_WAIT period. Added `websocket.setsockopt(socket.SOL_SOCKET, socket.SO_REUSEADDR, 1)`.
- **BUG-05** — `class_rotary_encoder.py` `get_rotary_encoder()`: Used `global isRotaryEncoder` which referred to a variable in the method's own module scope — never defined there — causing `NameError` at runtime. Replaced with an `is_enabled=True` parameter; callers pass their own flag.
- **BUG-06** — `main.py` `RotaryController()`: `rotary_val_old` was never updated after reading the encoder. The comparison always ran against the initial value (0), making the encoder fire on every timer tick once turned. Added `rotary_val_old = r_value` inside the change-detected branch.
- **BUG-07** — `main.py` `Button_R_switch()`: `txt = Button_R_switch` assigned the function object instead of a string. Changed to `txt = "Button_R_switch"`.
- **BUG-08** — `main.py`: `import gc` appeared twice (second occurrence with trailing comment). Removed the duplicate.
- **BUG-09** — `main.py` `RotaryController()`: `r_value != None` identity comparison used `==` instead of `is not`. Changed to `r_value is not None`.
- **BUG-10** — `main.py` `thread_webserver()`: All `conn.send()` calls passed `str` literals instead of `bytes`. MicroPython `usocket.send()` requires bytes-like objects. Changed all header sends to byte literals (`b"…"`) and added `.encode()` to `conn.sendall(response)`.
- **BUG-11** — `main.py` `thread_webserver()`: Bare `except:` silently discarded all exceptions. Changed to `except Exception as e:` with a debug log.
- **BUG-12** — `class_wifi_connection.py` `is_connected()`: Called `self.wifi.check_connection()` on a `network.WLAN` object which has no such method. Changed to `self.check_connection()`.
- **BUG-13** — `class_humidity_sensor.py` `get_humidity_and_temperature()`: Bare `except:` swallowed all errors. Changed to `except Exception:`.
- **BUG-14** — `class_debug.py` `debug()`: String concatenation `ctx + " " + message` raised `TypeError` when either argument was `None`. Changed to `str(ctx) + " " + str(message)`.

### Added

- **Hardware Watchdog (WDT)** — `main.py`: A 15-second WDT (`machine.WDT(timeout=15000)`) is started after WiFi connects. This is > the 10-second WiFi reconnect timeout so reconnect attempts complete before the WDT fires.
- **Loop-counter main loop** — `main.py`: The `while True` loop now runs at `LOOP_MS = 100 ms` and feeds the WDT on every iteration. A counter (`_loop_count % WIFI_CHECK_TICKS`) triggers the WiFi health check every 60 seconds, replacing the former `sleep_ms(60000)` which would have caused a WDT reset.
- **Loop constants** — `main.py`: Added `LOOP_MS = 100` and `WIFI_CHECK_TICKS = 600` with inline comments explaining their relationship.
- **Docstrings** — All modules, public classes and public methods now have docstrings: `main.py`, `class_pwm.py`, `class_debounce.py`, `class_debug.py`, `class_humidity_sensor.py`, `class_wifi_connection.py`, `class_rotary_encoder.py`, `web_html.py`, `boot.py`.

### Changed

- `main.py` `RotaryController()`: Comment corrected from "tranlate" to "translate".
- `class_rotary_encoder.py` `get_rotary_encoder()`: Signature changed from `(self, sw, val_old)` to `(self, sw, val_old, is_enabled=True)`. Call site in `main.py` updated accordingly. Backwards-compatible (default `True`).
- `class_wifi_connection.py` docstring: Replaced informal class docstring with structured Google-style docstring.

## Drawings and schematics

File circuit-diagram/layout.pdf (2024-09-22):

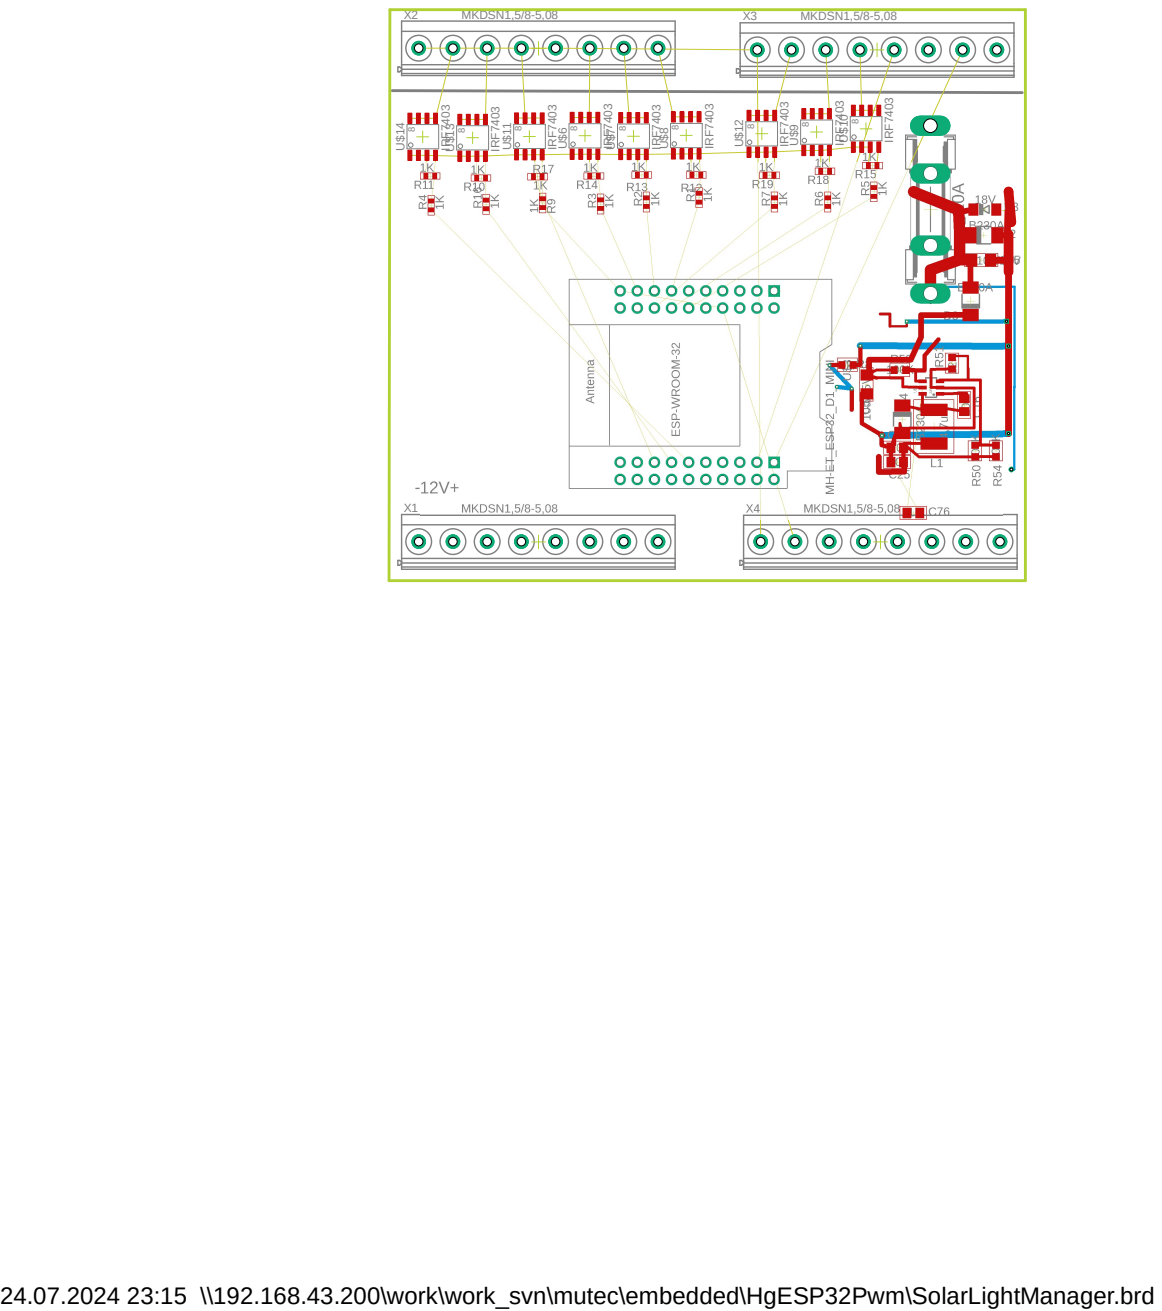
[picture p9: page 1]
MKDSN1,5/8-5,08; MKDSN1,5/8-5,08 IRF7403; IRF7403; IRF7403 IRF7403

24.07.2024 23:15 \\192.168.43.200\work\work_svn\mutec\embedded\HgESP32Pwm\SolarLightManager.brd

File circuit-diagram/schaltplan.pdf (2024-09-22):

A

A

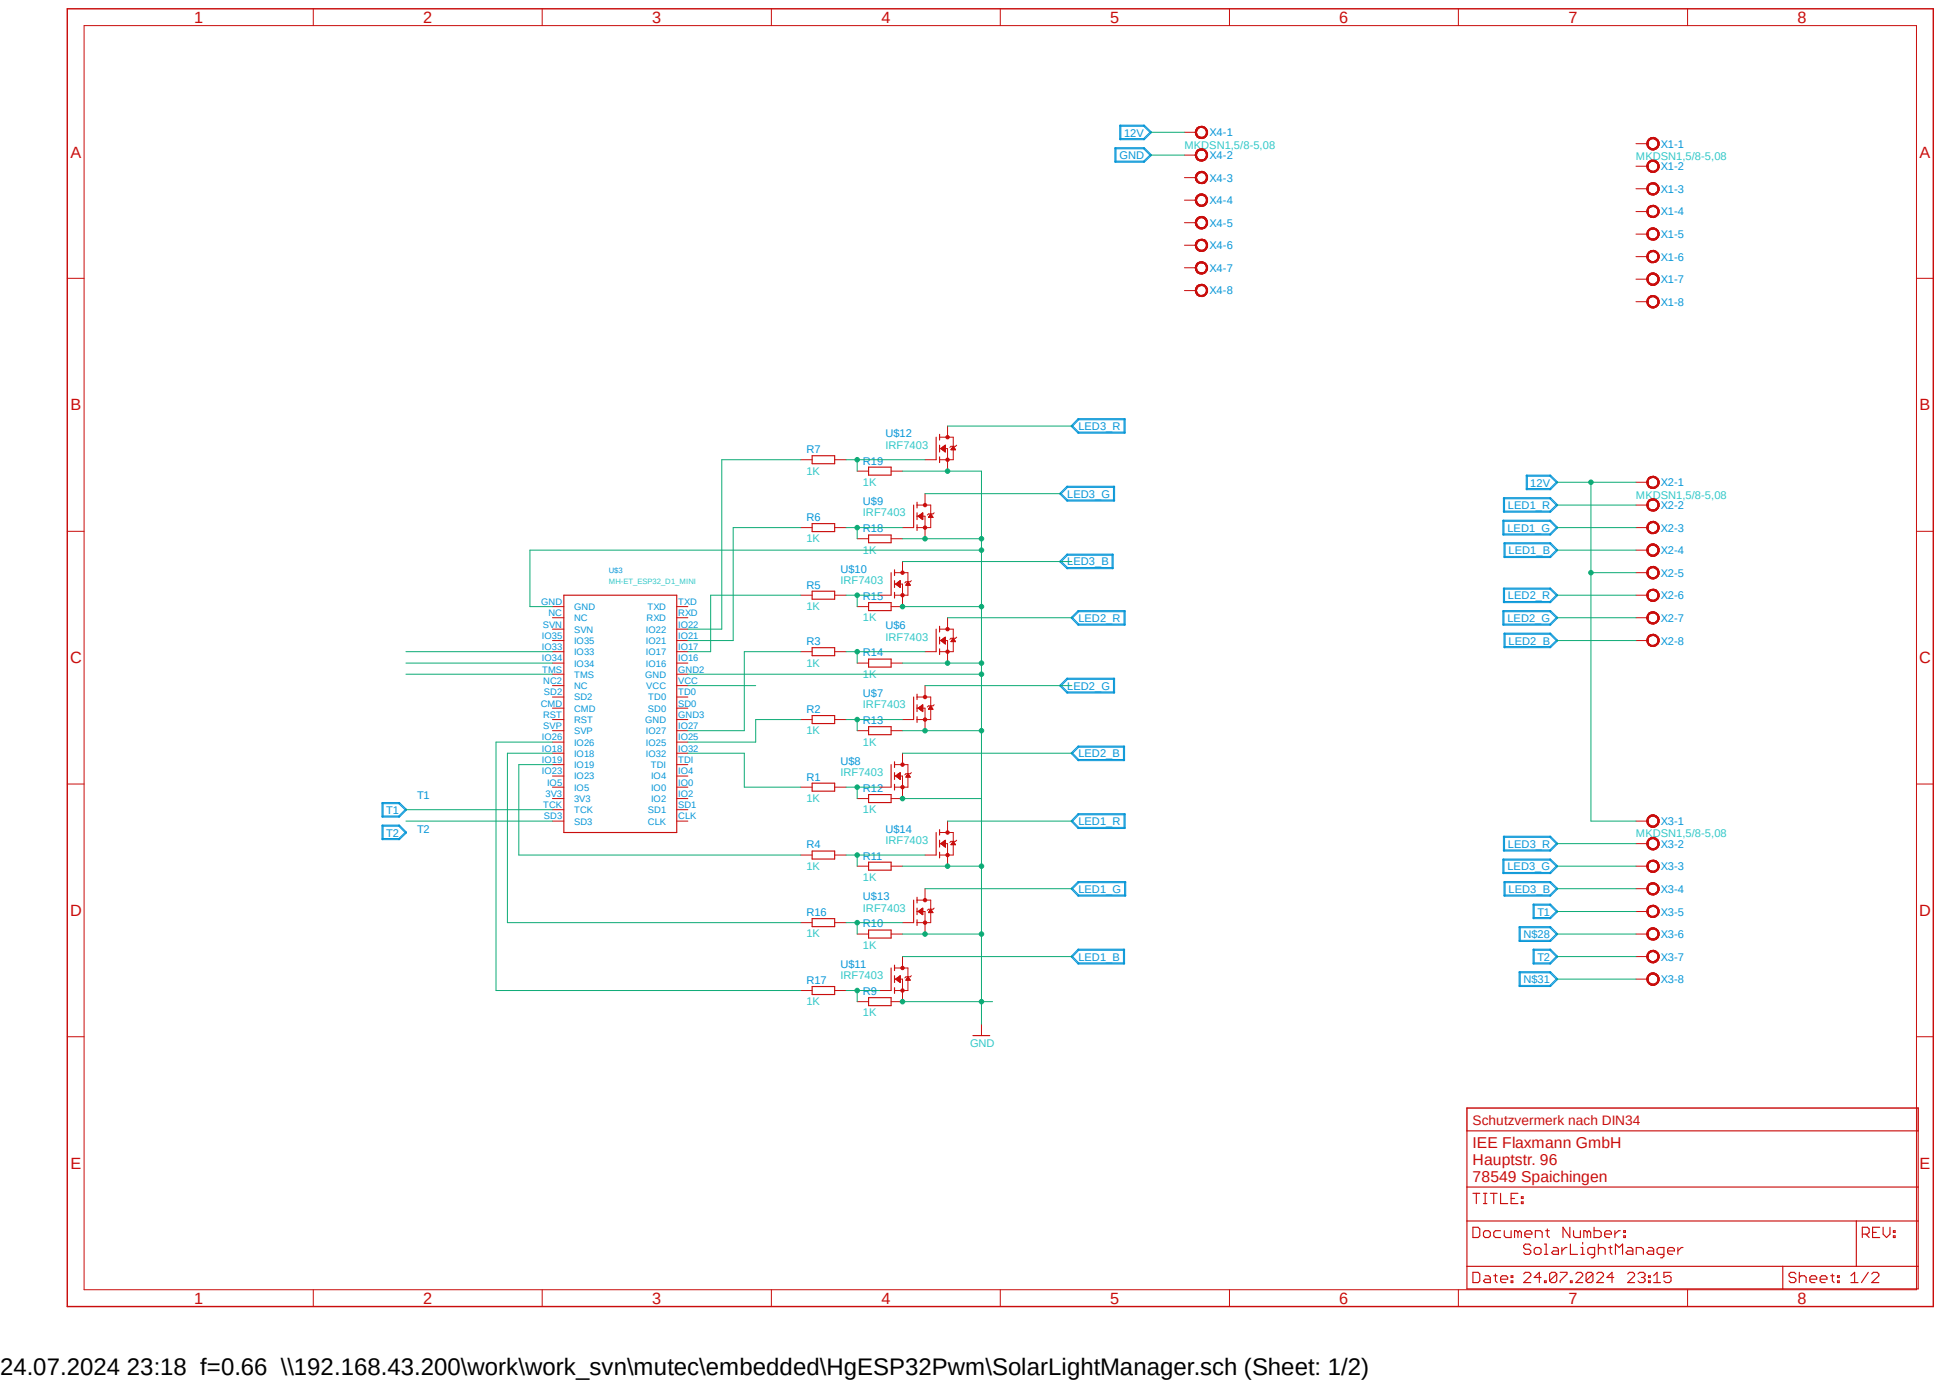
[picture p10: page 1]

Schutzvermerk nach DIN34 IEE Flaxmann GmbH

24.07.2024 23:18 f=0.66 \\192.168.43.200\work\work_svn\mutec\embedded\HgESP32Pwm\SolarLightManager.sch (Sheet: 1/2)

A

A

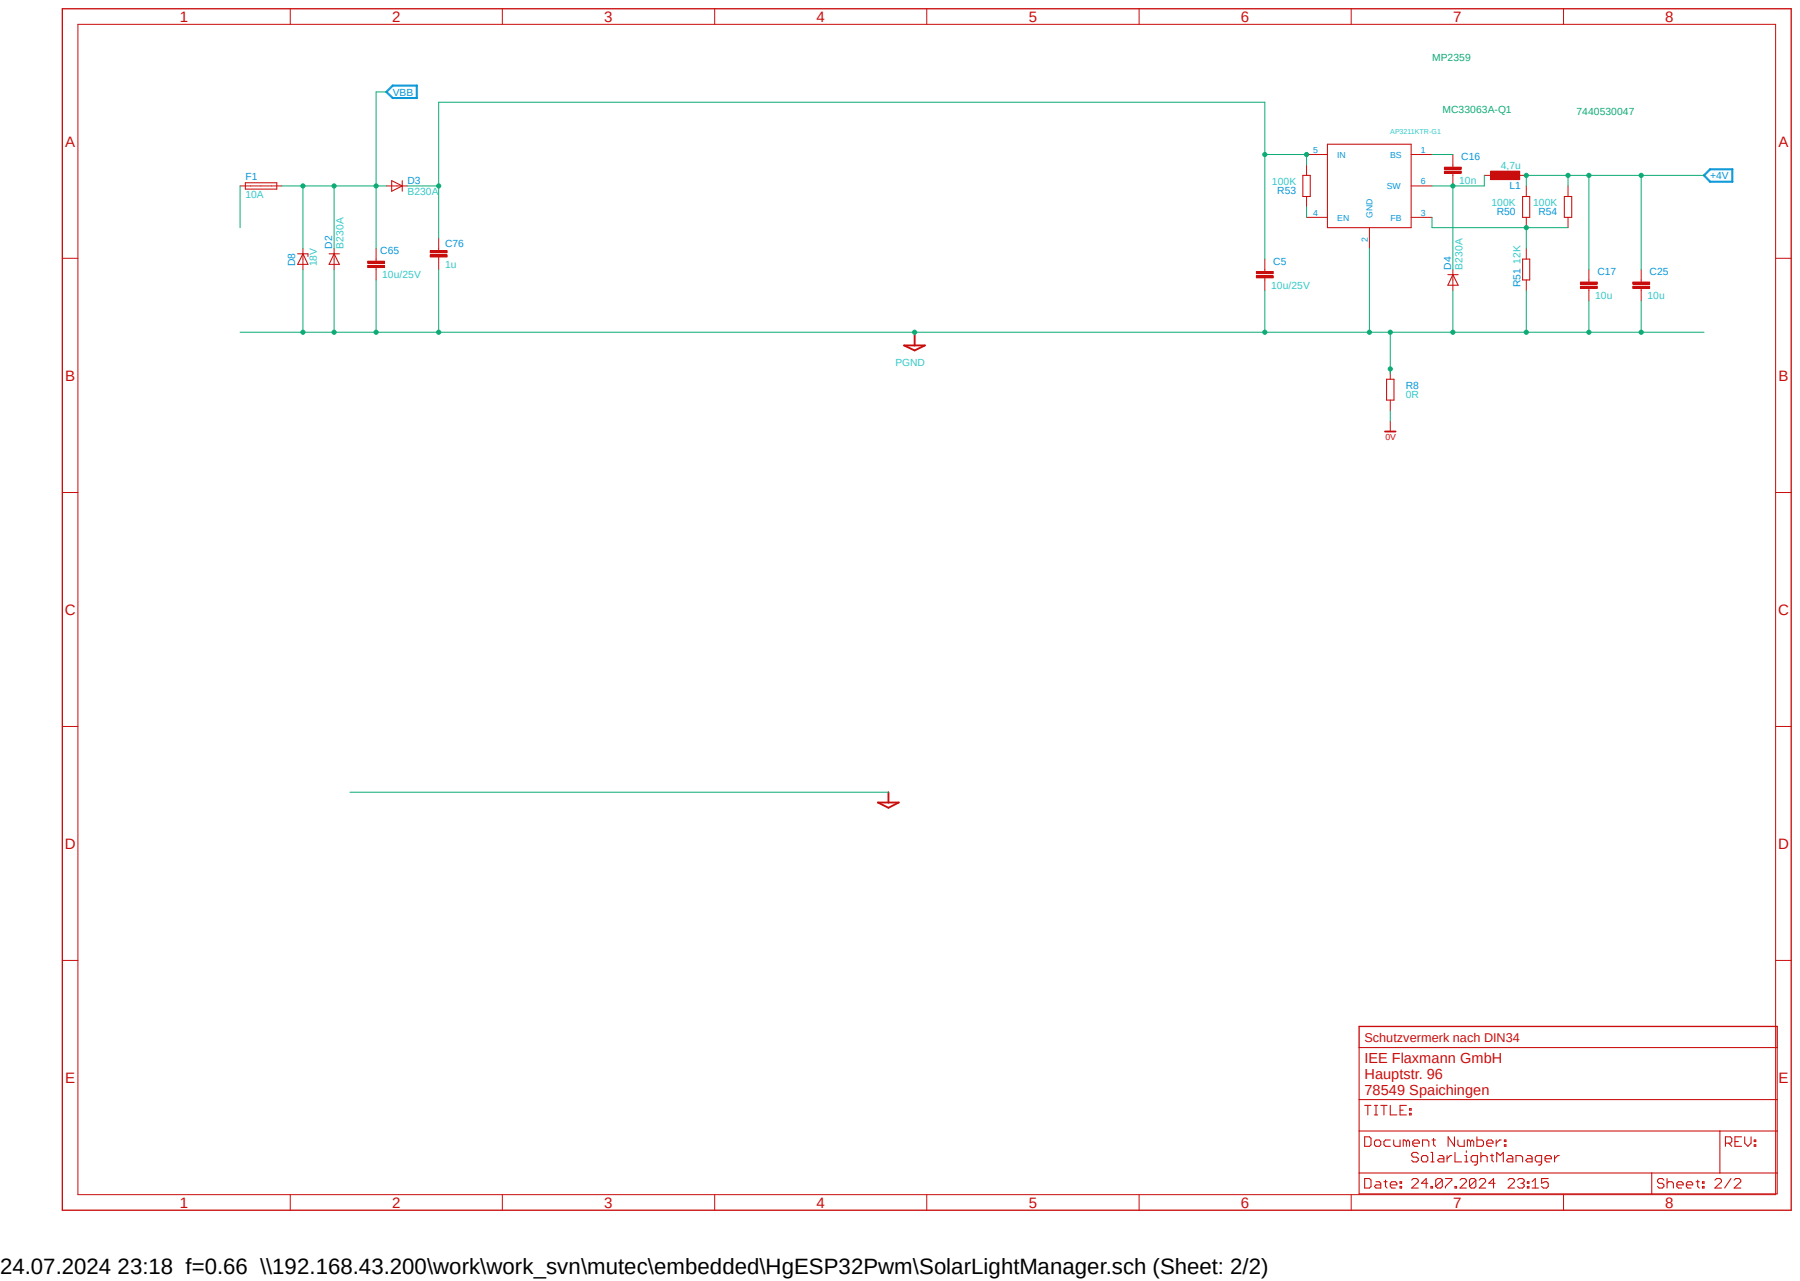
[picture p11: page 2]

Schutzvermerk nach DIN34 IEE Flaxmann GmbH

24.07.2024 23:18 f=0.66 \\192.168.43.200\work\work_svn\mutec\embedded\HgESP32Pwm\SolarLightManager.sch (Sheet: 2/2)

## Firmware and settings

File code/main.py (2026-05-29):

"""
Main application for ESP32 LED-Strip Observatory Lighting control.

Controls three RGB LED strips for the Sternwarte Höfingen observatory via PWM.
Provides a web interface (port 80), hardware buttons, and a rotary encoder
for brightness and colour control. A DHT11 sensor reports ambient temperature
and humidity on the web UI.

Hardware:
    - ESP32 (AZ-Delivery D1 Mini or compatible)
    - 3× RGB LED strip (common-cathode, PWM-driven)
    - 2× push button (white/red light toggle)
    - 1× rotary encoder with push button (brightness)
    - 1× DHT11 temperature/humidity sensor
    - Built-in LED on GPIO 2

Pin mapping (see constants below):
    PIN_DHT       = 0   DHT11 data
    PIN_STRIP_1R  = 27  Strip 1 Red
    PIN_STRIP_1G  = 25  Strip 1 Green
    PIN_STRIP_1B  = 32  Strip 1 Blue
    PIN_STRIP_2R  = 22  Strip 2 Red
    PIN_STRIP_2G  = 21  Strip 2 Green
    PIN_STRIP_2B  = 17  Strip 2 Blue
    PIN_STRIP_3R  = 19  Strip 3 Red
    PIN_STRIP_3G  = 18  Strip 3 Green
    PIN_STRIP_3B  = 26  Strip 3 Blue
    PIN_BUTTON_W  = 13  White-light button
    PIN_BUTTON_R  = 10  Red-light button
    PIN_BUTTON_D  = 14  Rotary encoder push button
    PIN_CLK       = 33  Rotary encoder CLK
    PIN_DT        = 34  Rotary encoder DT
"""
# Lighting for our Observatory with LED-Stripes
# Observatory: https://www.sternwarte-hoefingen.de
# Code by Hagen and Ramona Glötter
# Source and Docs: https://github.com/hagen-gloetter/LED-Strips-ESP32

# GPIO Pins:
PIN_DHT = 0 # Humidity sensor
PIN_STRIP_1R = 27
PIN_STRIP_1G = 25
PIN_STRIP_1B = 32
PIN_STRIP_2R = 22
PIN_STRIP_2G = 21
PIN_STRIP_2B = 17
PIN_STRIP_3R = 19
PIN_STRIP_3G = 18
PIN_STRIP_3B = 26
PIN_BUTTON_W = 13 # T1
PIN_BUTTON_R = 10 # T2
# Rotary
PIN_BUTTON_D = 14 # Switch
PIN_CLK = 33
PIN_DT = 34

# System Includes
from time import sleep_ms
from machine import Pin, Timer
import _thread
import time
import machine
import gc
import network
# Custom Includes
from class_debug import debug_init, debug, get_debug_msg
from class_rotary_encoder import RotaryIRQ
from class_pwm import LEDStrip
from class_debounce import debounced_Button
from class_humidity_sensor import HumiditySensor
# web_html is imported lazily AFTER WiFi connects to save RAM during scan
import class_wifi_connection
import ujson

try:
    import usocket as socket
except:
    import socket

debug_init()

# Load configuration
try:
    with open("config.json", "r") as f:
        config = ujson.load(f)
    Brightness = config.get("Brightness", 1024)
    Fade_speed = config.get("Fade_speed", 16)
    DebugLevel = config.get("DebugLevel", 4)
    LOOP_MS = config.get("LOOP_MS", 100)
    WIFI_CHECK_TICKS = config.get("WIFI_CHECK_TICKS", 300)
    auto_off_minutes = config.get("auto_off_minutes", 120)
    hostname = config.get("hostname", "ESP32-Huettenlicht")
    rotary_encoder_enabled = 1 if config.get("rotary_encoder_enabled", 0) else 0
    humidity_sensor_enabled = 1 if config.get("humidity_sensor_enabled", 1) else 0
    debug(3, __name__, "Configuration loaded from config.json")
except Exception as e:
    debug(2, __name__, f"Failed to load config.json: {e}, using defaults")
    Brightness = 1024
    Fade_speed = 16
    DebugLevel = 4
    LOOP_MS = 100
    WIFI_CHECK_TICKS = 300
    auto_off_minutes = 120
    hostname = "ESP32-Huettenlicht"
    rotary_encoder_enabled = 0
    humidity_sensor_enabled = 1

debug(4, __name__, "main.py start")

# setup LED
led = machine.Pin(2, machine.Pin.OUT)
CPU_Speed = machine.freq()
# machine.freq(int(CPU_Speed / 2)) # Brown Out Protection
# debug(4, __name__, f"machine.freq={CPU_Speed}")
# Buttons
Button_W_PIN = PIN_BUTTON_W
Button_R_PIN = PIN_BUTTON_R
Button_D_PIN = PIN_BUTTON_D
Button_W_Status = "OFF"
Button_R_Status = "OFF"
Button_D_Status = "OFF"
Button_Counter = 0
Light_W = "OFF"  # white
Light_R = "OFF"  # red
run_webserver = True
# wifi variables
wifi_status = None
wifi_ssid = None
wifi_ip = None
temperature = 0
humidity = 0


# setup LED Stripes
ColorRGB = [0, 0, 0]
ColorSollwerte = [0, 0, 0]

# Easter Egg and rapid-press state
EasterEgg_Mode = None  # None / "rainbow" / "random"
_ee_hue = 0  # current hue for rainbow mode (0-359)
_btn_w_rapid_count = 0
_btn_w_rapid_start = 0
_btn_r_rapid_count = 0
_btn_r_rapid_start = 0
RAPID_WINDOW_SHORT = 2000  # ms for 2x/4x brightness presets
RAPID_WINDOW_LONG = 6000   # ms for 10x easter egg
_auto_off_start = 0  # ticks_ms when light turned on, 0 = inactive

# init LED Stripes
# TODO  Listen übergeben
Strip1 = LEDStrip(ColorRGB[0], ColorRGB[1], ColorRGB[2], PIN_STRIP_1R, PIN_STRIP_1G, PIN_STRIP_1B)
Strip2 = LEDStrip(ColorRGB[0], ColorRGB[1], ColorRGB[2], PIN_STRIP_2R, PIN_STRIP_2G, PIN_STRIP_2B)
Strip3 = LEDStrip(ColorRGB[0], ColorRGB[1], ColorRGB[2], PIN_STRIP_3R, PIN_STRIP_3G, PIN_STRIP_3B)
Strip1.SetColor(ColorRGB[0], ColorRGB[1], ColorRGB[2])
Strip2.SetColor(ColorRGB[0], ColorRGB[1], ColorRGB[2])
Strip3.SetColor(ColorRGB[0], ColorRGB[1], ColorRGB[2])

def update_all_strips(r, g, b):
    """
    Update all three LED strips with the given RGB values.

    Args:
        r (int): Red duty cycle (0–1023).
        g (int): Green duty cycle (0–1023).
        b (int): Blue duty cycle (0–1023).

    Returns:
        None
    """
    global ColorRGB
    ColorRGB = [r, g, b]
    Strip1.SetColor(r, g, b)
    Strip2.SetColor(r, g, b)
    Strip3.SetColor(r, g, b)


def hsv_to_rgb_1023(h):
    """
    Convert HSV hue to RGB with full saturation and value at 10-bit scale.

    Integer-only arithmetic for MicroPython performance.

    Args:
        h (int): Hue angle 0–359.

    Returns:
        list: [R, G, B] each 0–1023.
    """
    # Sector 0-5, each 60 degrees
    sector = h // 60
    remainder = h - (sector * 60)  # 0-59
    # fractional part scaled to 0-1023
    f = (remainder * 1023) // 60
    nf = 1023 - f

    if sector == 0:
        return [1023, f, 0]
    elif sector == 1:
        return [nf, 1023, 0]
    elif sector == 2:
        return [0, 1023, f]
    elif sector == 3:
        return [0, nf, 1023]
    elif sector == 4:
        return [f, 0, 1023]
    else:
        return [1023, 0, nf]

r = RotaryIRQ(
    pin_num_clk=PIN_CLK,
    pin_num_dt=PIN_DT,
    min_val=0,
    max_val=10,
    reverse=True,
    range_mode=RotaryIRQ.RANGE_BOUNDED,
)
rotarySwitch = Pin(PIN_BUTTON_D, Pin.IN)
rotary_val_old = r.value()
isRotaryEncoder = rotary_encoder_enabled == 1
r.set_enabled(isRotaryEncoder)

# rotary encoder init end

if humidity_sensor_enabled:
    temperature_sensor = HumiditySensor(PIN_DHT)
else:
    temperature_sensor = None
    temperature = "NA"
    humidity = "NA"
    debug(4, __name__, "Humidity sensor disabled in config")

# Webserver start
WS_initstage = 0
websocket = ""

# setup Wifi
global wifi
gc.collect()
debug(4, __name__, f"Free RAM before WiFi: {gc.mem_free()} bytes")
wifi = class_wifi_connection.WifiConnect()
wifi.set_hostname(hostname)
(wifi_status, wifi_ssid, wifi_ip) = wifi.connect()
debug(4, __name__, "Wifi connection established")

# Start WebREPL after WiFi STA is connected (moved from boot.py to save RAM during scan)
try:
    import webrepl
    webrepl.start()
    debug(4, __name__, "WebREPL started")
except Exception as e:
    debug(2, __name__, f"WebREPL failed: {e}")

# Import web_html AFTER WiFi connect to avoid RAM pressure during scan
gc.collect()
from web_html import web_page, debug_web_page, logs_web_page, web_css, config_web_page
debug(4, __name__, f"Free RAM after web_html import: {gc.mem_free()} bytes")


def get_websocket():
    """
    Create and bind the TCP server socket on port 80.

    Sets SO_REUSEADDR so the port is immediately available after a reboot.
    Stores the socket in the global ``websocket`` variable.

    Returns:
        None
    """
    global websocket
    debug(4, __name__, "Websocket init")
    websocket = socket.socket(socket.AF_INET, socket.SOCK_STREAM)
    websocket.setsockopt(socket.SOL_SOCKET, socket.SO_REUSEADDR, 1)
    websocket.bind(("", 80))
    websocket.listen(5)
    sleep_ms(500)
    debug(4, __name__, "Websocket done")


def thread_webserver(delay, name):
    """
    Webserver thread: accept HTTP requests and serve the control UI.

    Runs until ``run_webserver`` is set to False. Parses GET parameters
    for RGB colour, red/white toggle, Easter Eggs, config writes,
    reset requests, and JSON/CSS/debug endpoints.

    Args:
        delay (int): Unused legacy parameter.
        name (str): Thread name used in debug messages.

    Returns:
        None
    """
    global run_webserver
    while run_webserver == True:
        global JSONdata
        global websocket
        global Light_W
        global Light_R
        global ColorSollwerte
        global EasterEgg_Mode
        global _auto_off_start
        global _ee_hue
        global _btn_w_rapid_count
        global _btn_r_rapid_count
        global Fade_speed
        global auto_off_minutes
        global DebugLevel
        global hostname
        global isRotaryEncoder
        global rotary_val_old
        global humidity_sensor_enabled
        global temperature_sensor
        global temperature
        global humidity
        conn = None
        try:
            conn, addr = websocket.accept()
            request = conn.recv(1024)
            request = str(request)
            machine.idle()

            # Refresh sensor data opportunistically on web traffic so the UI
            # stays current without a dedicated sensor polling thread.
            if humidity_sensor_enabled and temperature_sensor is not None:
                (temperature, humidity) = temperature_sensor.get_humidity_and_temperature()

            # Parse the request directly from the first line. This keeps the
            # socket handling simple and predictable on MicroPython.
            r_index = request.find('/?r=')
            g_index = request.find('&g=')
            b_index = request.find('&b=')
            if r_index != -1 and g_index != -1 and b_index != -1:
                # Extract RGB values from the URL
                try:
                    r_value = int(request[r_index+4 : g_index])
                    g_value = int(request[g_index+3 : b_index])
                    # find end of blue value (space or & terminates)
                    b_end = request.find(" ", b_index+3)
                    if b_end == -1:
                        b_end = request.find("&", b_index+3)
                    if b_end == -1:
                        b_end = len(request)
                    b_value = int(request[b_index+3 : b_end])

                    # Validate if the values are in the range of 0 to 255
                    if 0 <= r_value <= 255 and 0 <= g_value <= 255 and 0 <= b_value <= 255:
                        debug(4, __name__, f"Received valid RGB values: R={r_value}, G={g_value}, B={b_value}")
                        # Scale from 0-255 to 0-1023 for internal PWM resolution
                        ColorSollwerte = [r_value * 1023 // 255, g_value * 1023 // 255, b_value * 1023 // 255]
                        # Custom color: disable white/red mode so timer doesn't override
                        Light_W = "OFF"
                        Light_R = "OFF"
                        EasterEgg_Mode = None
                        _auto_off_start = 0
                        # Update the LED strips with the new color
                        update_all_strips(ColorSollwerte[0], ColorSollwerte[1], ColorSollwerte[2])
                    else:
                        debug(4, __name__, "Invalid RGB values received. Ignoring request.")
                except ValueError:
                    debug(4, __name__, "Invalid RGB input detected. Could not convert to integers.")
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

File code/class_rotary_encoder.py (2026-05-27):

"""
ESP32 hardware-interrupt rotary encoder driver.

Extends the platform-independent ``Rotary`` base class with GPIO IRQ
handling. Also provides a convenience method ``get_rotary_encoder()``
that filters repeated values for use in polling loops.

Usage::

    from class_rotary_encoder import RotaryIRQ
    r = RotaryIRQ(pin_num_clk=33, pin_num_dt=34, min_val=0, max_val=10,
                  reverse=True, range_mode=RotaryIRQ.RANGE_BOUNDED)
    old = r.value()
    while True:
        new = r.get_rotary_encoder(sw_pin, old)
        if new is not None:
            old = new

Hardware:
    - CLK pin: GPIO 33 (in main.py)
    - DT  pin: GPIO 34 (in main.py)
    - SW  pin: GPIO 14 (not used inside this class)
"""
# The MIT License (MIT)
# Copyright (c) 2020 Mike Teachman
# https://opensource.org/licenses/MIT

# Platform-specific MicroPython code for the rotary encoder module
# ESP8266/ESP32 implementation

# Documentation:
#   https://github.com/MikeTeachman/micropython-rotary

from machine import Pin
from rotary import Rotary
from sys import platform
from time import sleep_ms
from class_debug import debug

class RotaryIRQ(Rotary):

    def __init__(self, pin_num_clk, pin_num_dt, min_val=0, max_val=10, reverse=False, range_mode=Rotary.RANGE_UNBOUNDED, pull_up=False, half_step=False, invert=False):
        """
        Initialise the GPIO-backed rotary encoder driver.

        Args:
            pin_num_clk (int): GPIO number for the CLK signal.
            pin_num_dt (int): GPIO number for the DT signal.
            min_val (int): Minimum encoder value.
            max_val (int): Maximum encoder value.
            reverse (bool): Reverse the rotation direction when True.
            range_mode (int): Rotary range mode from the base class.
            pull_up (bool): Enable internal pull-ups on both inputs.
            half_step (bool): Enable half-step decoding.
            invert (bool): Invert the interpreted direction.

        Returns:
            None
        """

        super().__init__(min_val, max_val, reverse, range_mode, half_step, invert)

        if pull_up == True:
            self._pin_clk = Pin(pin_num_clk, Pin.IN, Pin.PULL_UP)
            self._pin_dt = Pin(pin_num_dt, Pin.IN, Pin.PULL_UP)
        else:
            self._pin_clk = Pin(pin_num_clk, Pin.IN)
            self._pin_dt = Pin(pin_num_dt, Pin.IN)

        self._enable_clk_irq(self._process_rotary_pins)
        self._enable_dt_irq(self._process_rotary_pins)

    def _enable_clk_irq(self, callback=None):
        """
        Enable interrupts for the CLK pin.

        Args:
            callback (callable | None): IRQ handler to call on pin changes.

        Returns:
            None
        """
        self._pin_clk.irq(
            trigger=Pin.IRQ_RISING | Pin.IRQ_FALLING,
            handler=callback)

    def _enable_dt_irq(self, callback=None):
        """
        Enable interrupts for the DT pin.

        Args:
            callback (callable | None): IRQ handler to call on pin changes.

        Returns:
            None
        """
        self._pin_dt.irq(
            trigger=Pin.IRQ_RISING | Pin.IRQ_FALLING,
            handler=callback)

    def _disable_clk_irq(self):
        """Disable interrupts for the CLK pin.

        Returns:
            None
        """
        self._pin_clk.irq(handler=None)

    def _disable_dt_irq(self):
        """Disable interrupts for the DT pin.

        Returns:
            None
        """
        self._pin_dt.irq(handler=None)

    def _hal_get_clk_value(self):
        """Return the current logic level of the CLK pin.

        Returns:
            int: ``0`` or ``1``.
        """
        return self._pin_clk.value()

    def _hal_get_dt_value(self):
        """Return the current logic level of the DT pin.

        Returns:
            int: ``0`` or ``1``.
        """
        return self._pin_dt.value()

    def _hal_enable_irq(self):
        """Enable both rotary input IRQs.

        Returns:
            None
        """
        self._enable_clk_irq(self._process_rotary_pins)
        self._enable_dt_irq(self._process_rotary_pins)

    def _hal_disable_irq(self):
        """Disable both rotary input IRQs.

        Returns:
            None
        """
        self._disable_clk_irq()
        self._disable_dt_irq()

    def _hal_close(self):
        """Release hardware resources used by the encoder.

        Returns:
            None
        """
        self._hal_disable_irq()

    def set_enabled(self, is_enabled):
        """
        Enable or disable encoder IRQ processing.

        Args:
            is_enabled (bool): When True the encoder IRQs are active.

        Returns:
            None
        """
        if is_enabled:
            self._hal_enable_irq()
        else:
            self._hal_disable_irq()
        
    def get_rotary_encoder(self, sw, val_old, is_enabled=True):
        """
        Return the current encoder value if it changed since *val_old*.

        Args:
            sw (Pin): The rotary encoder push-button pin (reserved for
                future enable/disable toggle; currently unused).
            val_old (int): The previously seen encoder value.
            is_enabled (bool): When False the encoder is ignored and
                ``None`` is always returned.

        Returns:
            int | None: New value if the encoder moved, else ``None``.
        """
        if is_enabled:
            val_new = self.value()
            if val_old != val_new:
                val_old = val_new
                return val_new
        
#r = RotaryIRQ(
#    pin_num_clk=33,
#    pin_num_dt=34,
#    min_val=1,
#    max_val=255,
#    reverse=True,
#    range_mode=RotaryIRQ.RANGE_WRAP)

#sw = Pin(14, Pin.IN)
#sw_val_old = sw.value()
#val_old = r.value()

isRotaryEncoder = True

#while True:
#    r.get_rotary_encoder()
#    sleep_ms(200)

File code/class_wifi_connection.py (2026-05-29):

import ujson
import network
from network import WLAN
import machine
from machine import Timer
import sys
from time import sleep_ms
import utime  # Verwende utime f�r Zeitmessung in MicroPython
from class_debug import debug

class WifiConnect:
    """
    Multi-SSID WiFi connection manager for ESP32.

    Reads credentials from ``secrets_wifi.json`` (a JSON object mapping
    SSID → password). Scans for known networks and connects to the first
    match. Provides reconnect logic for use in the main loop.

    Usage::

        import class_wifi_connection
        wifi = class_wifi_connection.WifiConnect()
        wifi_status, wifi_ssid, wifi_ip = wifi.connect()
        # Later in main loop:
        wifi.check_connection()

    Notes:
        ``secrets_wifi.json`` must exist on the device filesystem before
        ``connect()`` is called.
    """

    def __init__(self):
        """
        Initialise cached WiFi state and the default DHCP hostname.

        Returns:
            None
        """
        self.wifi_ssid = "offline"
        self.wifi_pw = "hidden"
        self.wifi_ip = "offline"
        self.wifi_status = "offline"
        self.wifi = None
        self.hostname = "ESP32-Huettenlicht"

    def set_hostname(self, name):
        """
        Set the DHCP hostname used on the next WiFi connect/reconnect.

        Args:
            name (str): Hostname announced to the DHCP server.

        Returns:
            None
        """
        self.hostname = name

    def connect(self):
        """
        Load credentials from ``secrets_wifi.json`` and connect.

        Scans for available networks and tries each SSID listed in the
        credentials file until a connection is established.

        The scan is performed once up front so reconnect attempts can reuse
        the last known SSID/password pair without rescanning every time.

        Returns:
            list: ``[status (str), ssid (str), ip (str)]``.
                  *status* is ``"online"`` on success, ``"offline"`` on failure.
        """
        debug(4, __name__, "connect wifi called")
        fn_secrets = "secrets_wifi.json"
        debug(4, __name__, "WiFi debug: opening secrets file")
        try:
            with open(fn_secrets) as f:
                wlan_json = ujson.load(f)
        except Exception as e:
            debug(4, __name__, f"!!!!!!!!!!!!!!!! ERROR !!!!!!!!!!!!!!!! File not found {fn_secrets}: {e}")
            return ("offline", "offline", "offline")
        else:
            debug(4, __name__, f"connect wifi called with {fn_secrets}")
            try:
                import gc
                debug(4, __name__, "WiFi debug: free RAM before WLAN object: " + str(gc.mem_free()))
            except Exception:
                pass
            debug(4, __name__, "WiFi step: create STA interface")
            self.wifi = network.WLAN(network.STA_IF)
            debug(4, __name__, "WiFi debug: STA interface object created")
            debug(4, __name__, "WiFi step: enable STA interface")
            self.wifi.active(True)
            debug(4, __name__, "WiFi step: STA interface enabled")
            try:
                debug(4, __name__, "WiFi debug: status after active(True): " + str(self.wifi.status()))
            except Exception as e:
                debug(4, __name__, "WiFi debug: status() failed: " + str(e))
            utime.sleep_ms(100)
            for ssid in wlan_json.keys():
                pwd = wlan_json[ssid]
                debug(4, __name__, "Trying to connect to SSID:" + ssid)
                (
                    self.wifi_status,
                    self.wifi_ssid,
                    self.wifi_ip,
                ) = self.try_wifi_connect(ssid, pwd)
                if self.wifi_status == "online":
                    break
            list = [self.wifi_status, self.wifi_ssid, self.wifi_ip]
            return list
            
            

    def try_wifi_connect(self, ssid=None, pwd=None):
        """
        Attempt a connection to a specific SSID with a 10-second timeout.

        Args:
            ssid (str): Network SSID. Defaults to stored ``wifi_ssid``.
            pwd (str): Network password. Defaults to stored ``wifi_pw``.

        Returns:
            list: ``[status, ssid, ip]`` — same format as :meth:`connect`.
        """
        if ssid is None:
            ssid = self.wifi_ssid
            pwd = self.wifi_pw
        try:
            debug(4, __name__, "WiFi debug: entering connect() for SSID: " + str(ssid))
            self.wifi.connect(ssid, pwd)
            debug(4, __name__, "WiFi debug: connect() returned for SSID: " + str(ssid))
            timeout = 10000
            start_time = utime.ticks_ms()
            debug(4, __name__, "WiFi debug: waiting for isconnected()")
            while not self.wifi.isconnected():
                if utime.ticks_diff(utime.ticks_ms(), start_time) > timeout:
                    debug(4, __name__, "Connection timeout reached")
                    break
                machine.idle()  # Yield while waiting instead of busy-spinning.

            if self.wifi.isconnected():
                debug(4, __name__, "WiFi debug: isconnected() became True")
                self.wifi_status = "online"
                self.wifi_ssid = ssid
                self.wifi_pw = pwd
                self.wifi_ip = self.wifi.ifconfig()[0]
                debug(4, __name__, "Connected to " + self.wifi_ssid)
                debug(4, __name__, " with IP address: " + self.wifi_ip)
            else:
                try:
                    debug(4, __name__, "WiFi debug: final status before failure: " + str(self.wifi.status()))
                except Exception as status_error:
                    debug(4, __name__, "WiFi debug: final status() failed: " + str(status_error))
                raise Exception("Connection failed")

        except Exception as e:
            debug(4, __name__, f"Failed to connect to any known network: {e}")
            self.wifi_status = "offline"
            self.wifi_ssid = "offline"
            self.wifi_ip = "offline"
            self.wifi.disconnect()
        return [self.wifi_status, self.wifi_ssid, self.wifi_ip]

    def get_wifi_status(self):
        """
        Return the cached connection state without triggering reconnects.

        Returns:
            list: ``[status, ssid, ip]`` from the cached state.
        """
        list = [self.wifi_status, self.wifi_ssid, self.wifi_ip]
        return list

    def isconnected(self):
        """
        Proxy to ``network.WLAN.isconnected()`` for existing callers.

        Returns:
            bool: ``True`` when the WLAN interface is connected.
        """
        return self.wifi.isconnected()

    def check_connection(self):
        """
        Verify WiFi is still connected; reconnect automatically if not.
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

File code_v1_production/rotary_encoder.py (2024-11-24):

# More details can be found in TechToTinker.blogspot.com
# George Bantique | tech.to.tinker@gmail.com

from machine import Pin
from time import sleep_ms
from rotary_irq_esp import RotaryIRQ
from class_debug import debug


r = RotaryIRQ(
    pin_num_clk=33,
    pin_num_dt=34,
    min_val=1,
    max_val=255,
    reverse=True,
    range_mode=RotaryIRQ.RANGE_WRAP)
sw = Pin(14, Pin.IN)
val_old = r.value()
isRotaryEncoder = True
#debug(4, __name__, "rotary_encoder loaded")

# Debouncing function for switch
def debounce(pin):
    sleep_ms(50)  # Debounce time
    return pin.value()

def get_rotary_encoder():
    global isRotaryEncoder
    global sw
    # Switch toggling logic with debounce
#    if debounce(sw) == 1:
#        isRotaryEncoder = not isRotaryEncoder
#        if isRotaryEncoder == True:
#            debug(4, __name__, 'Rotary Encoder is now enabled.')
#        else:
#            debug(4, __name__, 'Rotary Encoder is now disabled.')
#
#    if isRotaryEncoder == True:
    global val_old
    val_new = r.value()
    if val_old != val_new:
        val_old = val_new
        debug(4, __name__, 'result = {}'.format(val_new))
        return val_new

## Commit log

2022-09-20 D1 mini ESP32 pinout
2022-09-22 Running Version with 2 gpio buttons
    2 pysical buttons on gpios
2022-09-23 Working Version
    Working
    + Webserver
    + JSON
    + Buttons
2022-09-25 rotary encoder working
2022-09-25 Fritzing Plan
    [ESP32-LED-Strips.fzz]
2022-09-29 Buttons are working - PWM not 100% working
2022-10-01 Debugging of boot-fails - no Wifi
    [main.py]
2022-10-05 Fade LEDs in an out
2022-10-06 Fader updated to Timer Interrupt
2022-10-06 Revert "Fader updated to Timer Interrupt"
    This reverts commit 77606fcc097561b6244634418970540b9c054a62.
    [main.py]
2022-10-22 Webserver Thread Fixed - Lights fixed - Rotary Contoller fixed
    [main.py, rotary_irq_esp.py, web_html.py]
2022-10-24 Completely Timer and Interrupt based Version - While True Loop removed
2022-12-17 Added Button longpress
2023-02-23 Added DHT to diagram
    [ESP32-LED-Strips-DHT.fzz]
2024-11-25 Sleep Timer angepasst
2024-11-29 Cast to string warning fix
    [main.py]
2026-03-28 feat: Add logging improvements, web interface presets, configuration file, and optimizations
    - Add separate logs web page (/logs.html) with JSON polling for live debugging
    - Implement config.json for easy adjustment of constants (brightness, fade speed, etc.)
    - Add more color presets (yellow, purple, cyan, orange) to web UI for better usability
    - Improve WiFi check interval to 30s and add edge-case logging (DHT errors, rotary status, WiFi scan)
    - Enhance button debounce robustness (10 cycles) and code deduplication with update_all_strips()
    - Update README and CHANGELOG for Session 4
    [class_debounce.py, class_humidity_sensor.py, class_wifi_connection.py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]
2026-05-25 feat(web-ui): modernize web interface with dark theme, color picker, and card layout
    - Replace table-based layout with responsive Flexbox/Grid card design
    - Add HTML5 color picker with live color preview div
    - Add visual preset grid (8 color buttons with colored backgrounds)
    - Add active ON/OFF state highlighting with glow effect
    - Dark astronomy theme (#0d1117 background, GitHub Dark palette)
    - Replace jQuery with vanilla JS fetch() in all pages (debug, logs)
    - Replace XHR with fetch API for polling and commands
    - Modernize CSS: system font stack, CSS custom properties, transitions
    - Total payload ~10 KB (ESP32-safe, self-contained, no external deps)
    - Update README (DE+EN) with new web int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
    [web_html.py]
2026-05-27 feat: add config UI, auto-off, easter eggs, hostname and optional rotary encoder
    - add rapid-press brightness presets (2x=50%, 4x=25%) and hold-to-dim
    - add configurable auto-off timer with default 120 minutes
    - add config page for fade speed, auto-off, debug level, hostname and reset
    - add reset button with confirmation dialog in the web interface
    - add configurable DHCP hostname (default: ESP32-Huettenlicht)
    - add optional rotary encoder toggle with persistent ON/OFF setting
    - readded Easter Egg modes via buttons and hidden web UI panel
    - disable rotary IRQ processing completely when encoder is set to OFF
    - redesign debug/log pages and extend main UI system/status links
    - extend JSON statu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
    [class_debounce.py, class_debug.py, class_humidity_sensor.py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]
2026-05-29 feat(config+runtime): stabilize webserver and add humidity sensor toggle
    fix(main): avoid local variable referenced before assignment in webserver thread
    fix(main): sync ColorRGB in update_all_strips to prevent color reset to black
    fix(main): respect rotary_encoder_enabled by disabling rotary timer/polling when off
    feat(main): add humidity_sensor_enabled config flag and runtime handling
    feat(web): add DHT11 sensor ON/OFF option in config page and save endpoint support
    fix(web): correct humidity select template rendering in config HTML
    [class_wifi_connection.py, main.py, web_html.py]
